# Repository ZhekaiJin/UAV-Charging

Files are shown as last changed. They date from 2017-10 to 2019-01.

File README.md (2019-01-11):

# UAV-Charging
Summer Intern Project for Totempower

* The circuit design could be viewed at the presentation
* Precise landing algorithm not disclosed here. (Contact me for full code)
* Full Info about Project [link](https://docs.google.com/presentation/d/1X8ElVUhhut9i08JShnHOG0T47P6EflJJdBkAeUSc1nc/edit?usp=sharing)

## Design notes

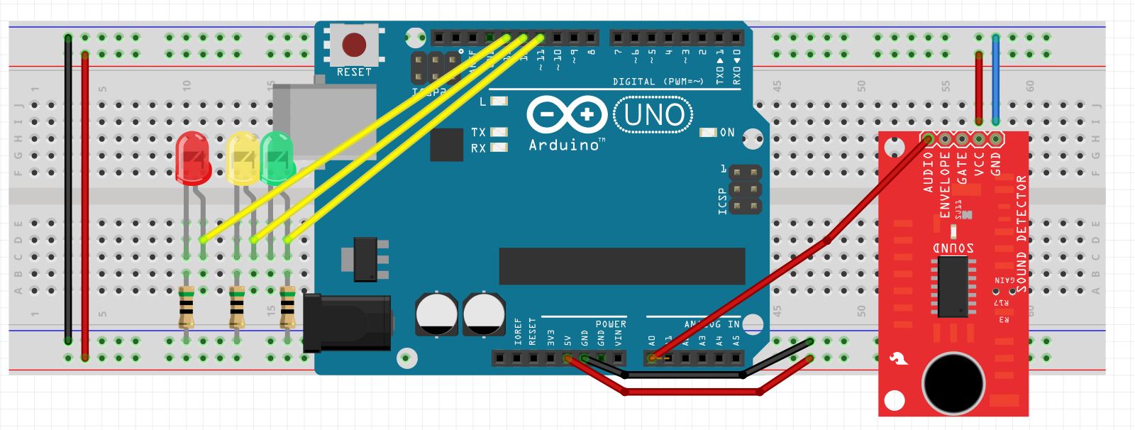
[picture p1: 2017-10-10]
Totem Project Zhekai Jin/realization 2/schematic.png

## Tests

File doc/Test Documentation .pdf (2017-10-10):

IDT WP3W-RK Testing Documentation

- Aiming to fully present all the features WP3W-RK implemented with WPC Qi Protocol
- connected with spark fun limo battery charging babysitter to implement charging for a single cell LiPo battery with 3.7V

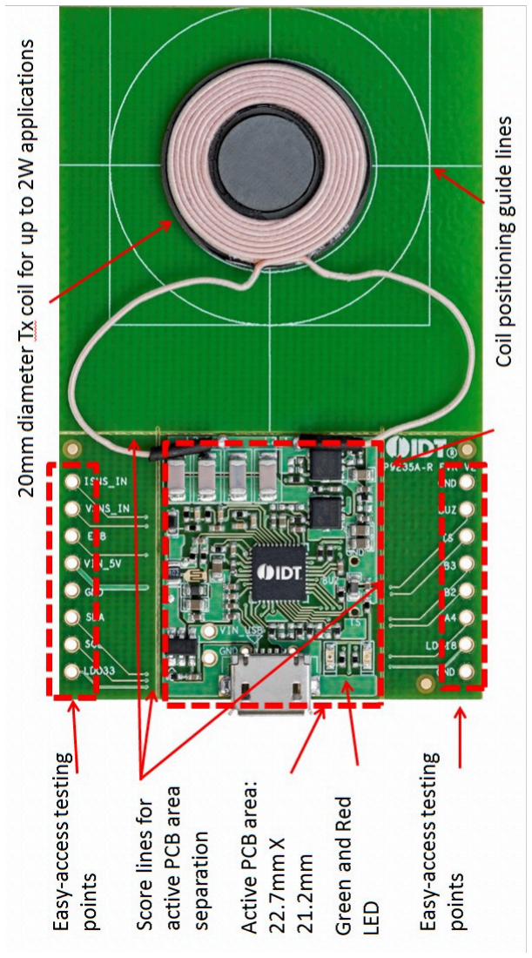
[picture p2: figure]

Transmitter

Pinout:

Vin_USB

Vin_5V

LDO 33

LDO 18

A4, B2,B3

BUZ

SDA

SCL

VSNS_IN

ISNS_IN

ENB

TS

GND

Receiver end:

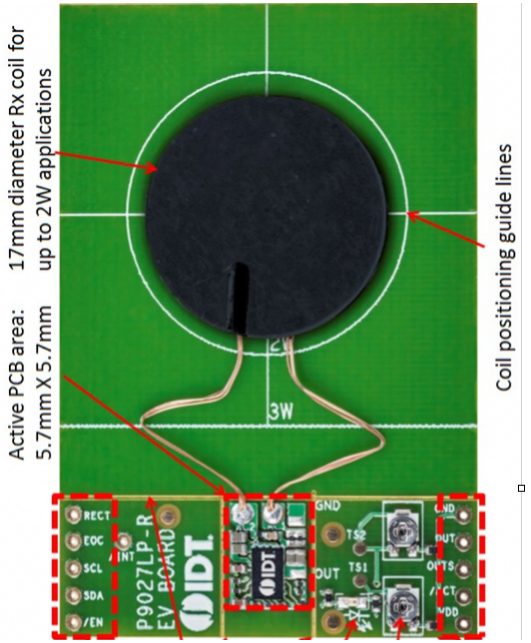
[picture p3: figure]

Pinout:

RECT

EOC

SCL

SDA

/EN

GND

OUT

OUTS

/ACT

VDD

Pinout specification(Transmitter):

Vin_USB | Micro usb power supply
Vin_5V | Input power supply (recommended 5V)
LDO 33 | Regulated 3.3 V output voltage used for internal device biasing.
LDO 18 | Regulated 1.8 V output voltage used for internal device biasing.
A4, B2,B3 | General purpose GPIO
BUZ | Buzzer pin output.
SDA /SCL | Data and Clock for I²C communication. Connect a 5.1 K resistor from this pin to VO_5
VSNS_IN | Voltage modulation signal input. (on test, just be the voltage sensing on the coil )
ISNS_IN | Current modulation signal input. (on test, just be the current sensing on the coil )
ENB | Active low enable pin. When connected to logic high, the device shuts down and consumes less than 25 µA of current. When connected to logic low, the device is in normal operation.
TS | Remote temperature sensing. Connect a 10 k NTC via a voltage divider to this pin.
GND | Ground connection

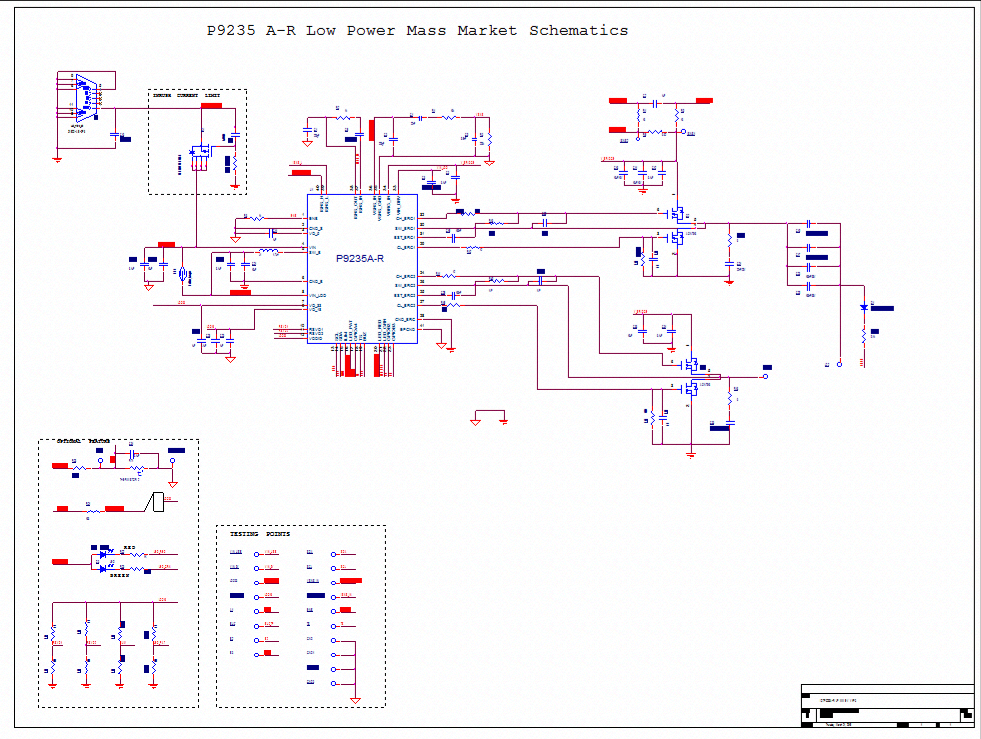
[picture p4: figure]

Transmitter Schematics

Tests on transmitter side:

- Basic functioning: Use a Micro USB connecter from the computer to power the transmitter, the red LED will blink once with the green led blink right after it, then both LEDs will light up for one second and turn off. When the receiver is put on the green LEDs on both the transmitter and the receiver will light up to show coupling

Power Consumption

Power the Transmitter with the Bench power supply (PSU, DC), if exactly 5V is supplied:

low power mode: voltage 5V current 0.01A when not in analog pinging and 0.03-0.05A(AC) in the pinging, according to estimate, the pinging is around 10 times per minute. (eye estimate)

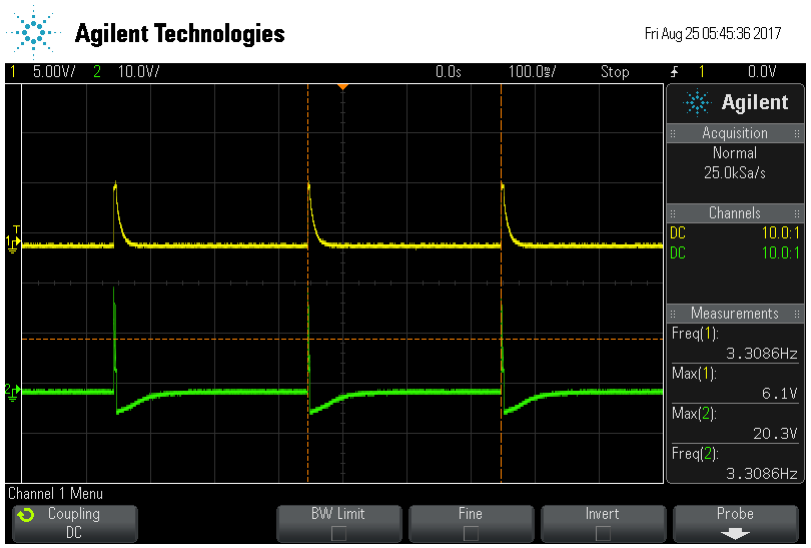
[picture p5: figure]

(Yellow from ISNS, Green from VSNS, Max scaled by 10X)

This demonstrates the analog pinging from the transmitter device to detect the presence of receiver coils. If the receiver is there, the transmitter will turn into digital pining to give enough energy pulse to active the receiver end circuit to start the handshake.

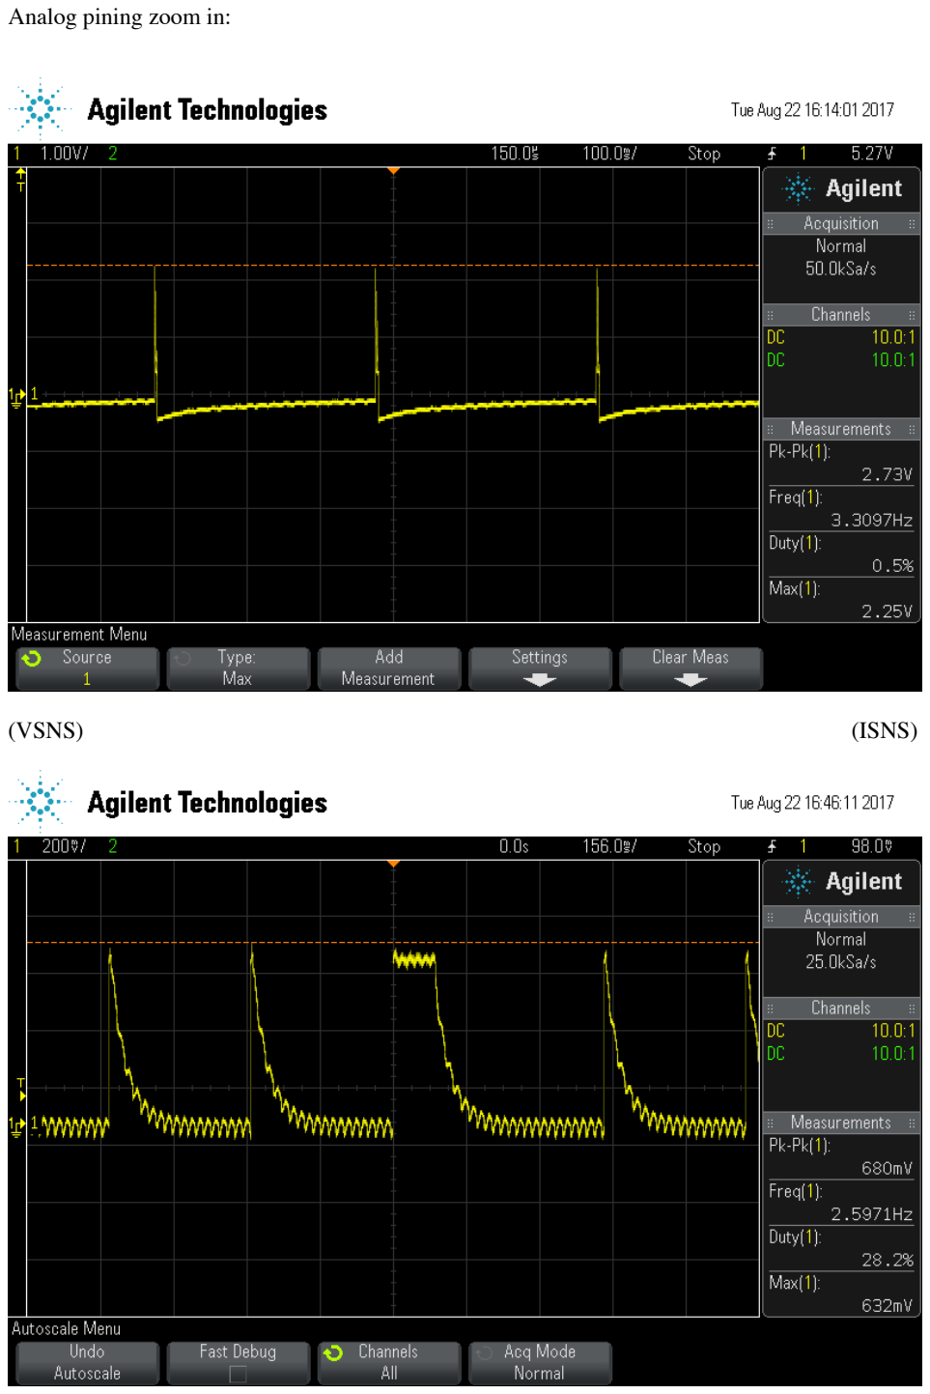
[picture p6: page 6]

Analog pining zoom in:

(VSNS) | (ISNS)

ISNS zoom in:

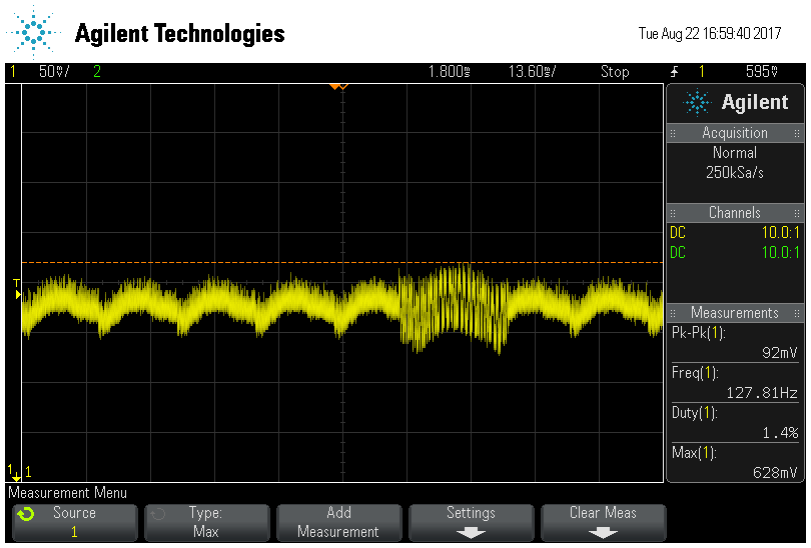
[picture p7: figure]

according to the acquired duty cycle the power consumption should be around 0.04 W (V*I *duty cycle) on the low power mode.

•by putting the receiver on the transmitter, a quick handshake should happen, with the digital pinging activate the device into identification and configuration phase where the Tx and Rx exchange information about protocol version and required voltage and maximum power output required. However, this process is too quick to capture on the Oscilloscope, will try to capture on future tests.

- the power transmission process then begin right after, with the receiver continuously sends back error packets on the coils back to the transmitter to fine-tune the power transmission. The received power packet can be viewed on the ISNS and VSNS both.

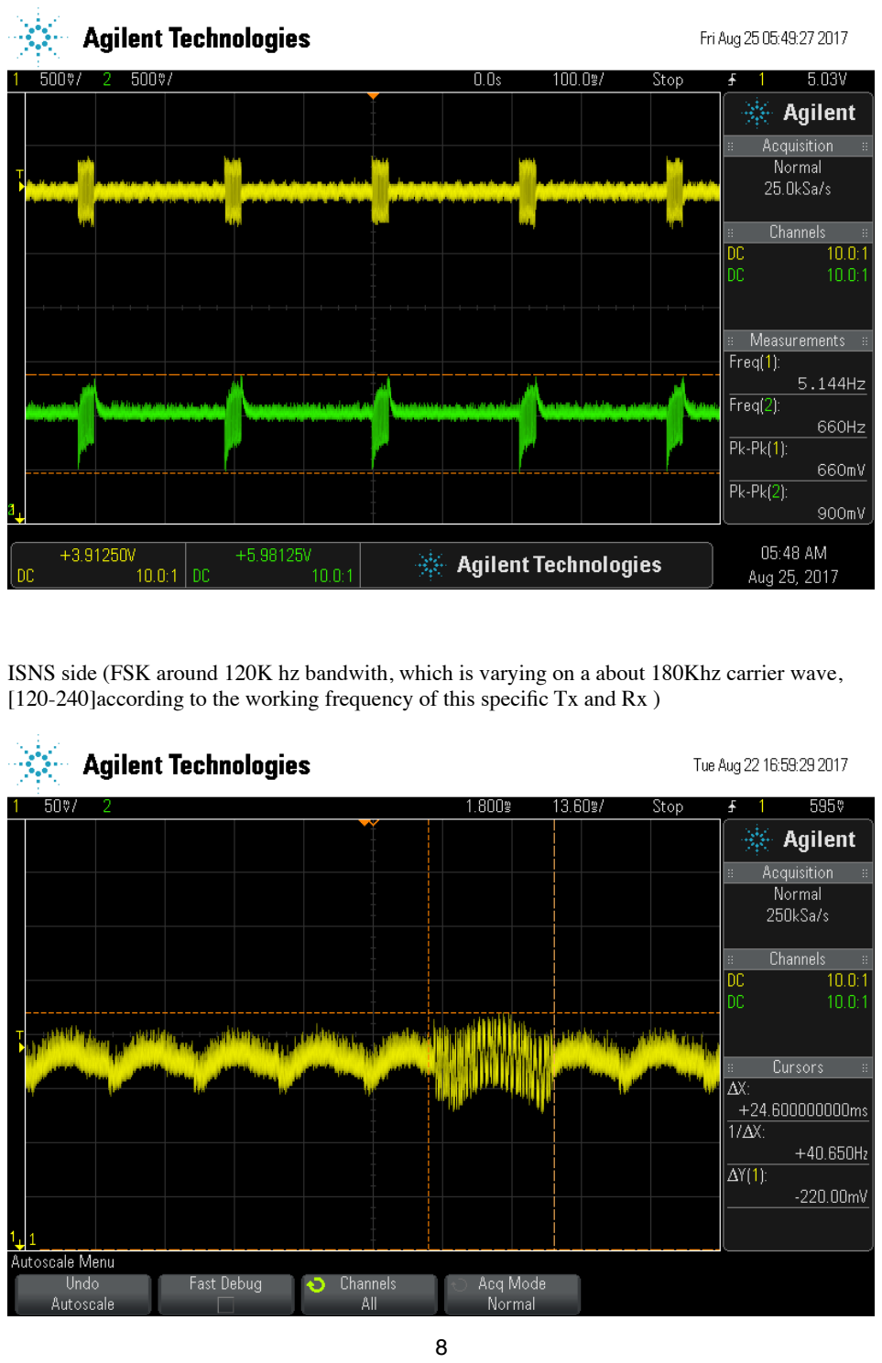
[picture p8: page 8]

ISNS side (FSK around 120K hz bandwith, which is varying on a about 180Khz carrier wave, [120-240]according to the working frequency of this specific Tx and Rx )

•On both sides

(Y for ISNS, G for VSNS)[10X mult]

to show the power transmission and the communication frequency.(packet frequency) [10X multi]

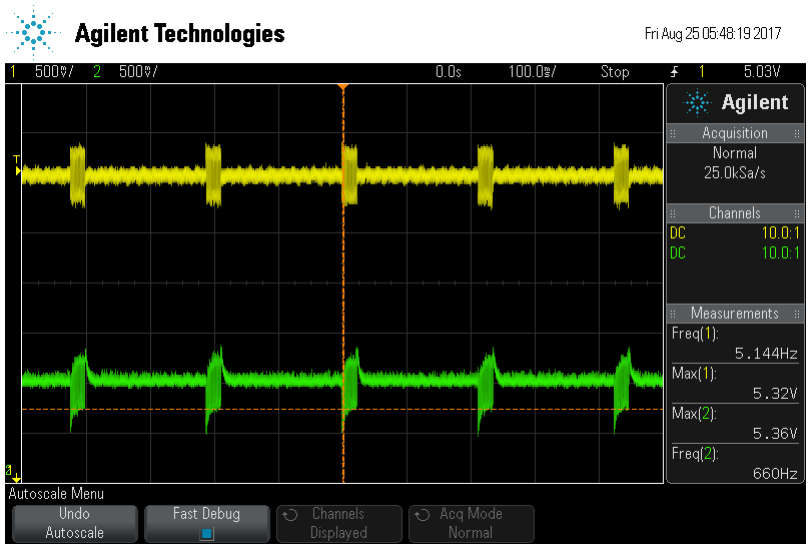
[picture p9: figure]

Observation from the PSU:

- coupling without load : Draw 0.17-0.22 A current from the power supply with no load (Vin >4.5V)
- coupling with load : Draw about 0.6 A current from the power supply with load on, around 3 W consumption from the load

Low Voltage alert : if the voltage is below 4.4V (from PSU), red LED will blink continuously to disallow charging, current will stay at 0.01 A without any pinging . if the supply is from 4.4 to 4.5 V, the pining will happen and no low power alert, but when coupling, and the signal strength packet is received, the coupling will stop (after 1s approximately), and the power transfer will sop and the transmitter goes into low power mode with red LED blinking (no pinging).

corresponding text in the data sheet :
“Under voltage protection: If the transmitter VIN is less than 4.5 V, the transmitter will

## shut down for five minutes, or until the VIN is cycled. off/on. “

High Voltage alert: if the voltage supplied is larger than 6.5V, the start up will be normal for the transmitter , but the receiver won’t allow coupling with the shake hand , the green LED on both devices wont even light up.

corresponding text in the data sheet :

## “Over voltage protection: If the transmitter VIN is greater than 5.5 V, and the system is

not in the Power Transfer mode, then the transmitter will shut down until the VIN is in the

## range of 4.5 V to 5.5 V. If the system is already in the Power Transfer mode, then the transmitter takes no action. “

- power consumption for the transmitter in low power mode : around 0.04 W

•LDO pinout voltage test: 3.3 and 1.8 V respectively, corresponding to the data sheet.

•BUZ: buzzer pin, untested

•ENB: =Enable Pin: If connected to high, power transmission of power will stop and the communication will turned to almost none value with 17mv AT MAXIMUM

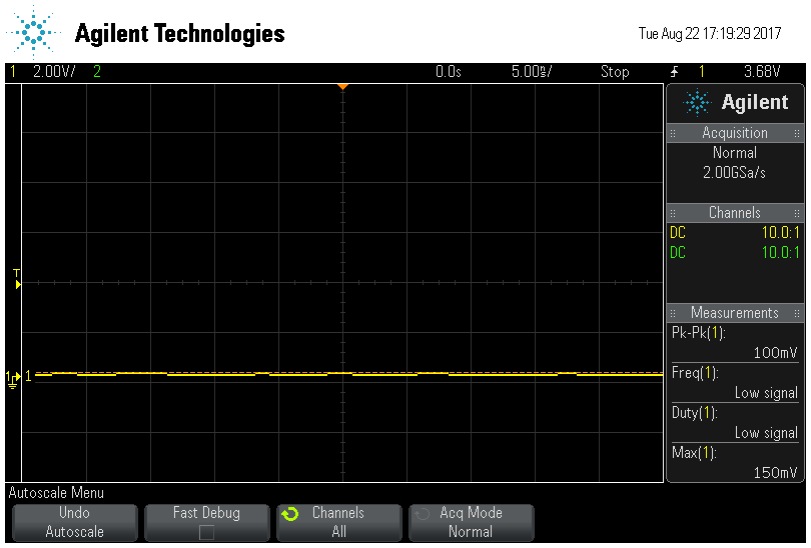
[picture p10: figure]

Receiver Pinout specification:

Pinout:
RECT | Output voltage of the synchronous rectifier bridge. Connect at least two 10 µF capacitors from this pin to PGND. The rectifier voltage dynamically changes as the load changes.
EOC | Active high end of charge input pin. When connected to logic high, the device sends end of power transfer packet (charge complete) to the transmitter to terminate power transfer and shuts down. The OUT pin is high impedance after P9027LP-R is shutdown
SCL | I 2C clock pin
SDA | I 2C data pin
/EN | Active low enable pin. Pulling this pin to logic high forces the device into shutdown mode. When connected to logic low, the device is enabled. Do not leave the pin floating.
GND | Power ground.
OUT | Regulated output voltage pin. Connect at least two 10 µF capacitors from this pin to PGND. The default voltage is set to 5V when VSET is directly shorted to GND.
OUTS | Feedback input pin. This pin must be connected directly to OUT pin to provide a regulated voltage.
/ACT | Active flag pin. Open drain output. Connect the cathode of the LED to this pin. When pulled low, it indicates connection between receiver and transmitter is established.
VDD | Charge pumps regulated 5 V supply to power the internal circuitry. Connect a 1 µF capacitor as close as possible from this pin to GND. Do not load the pin.

Schematics:

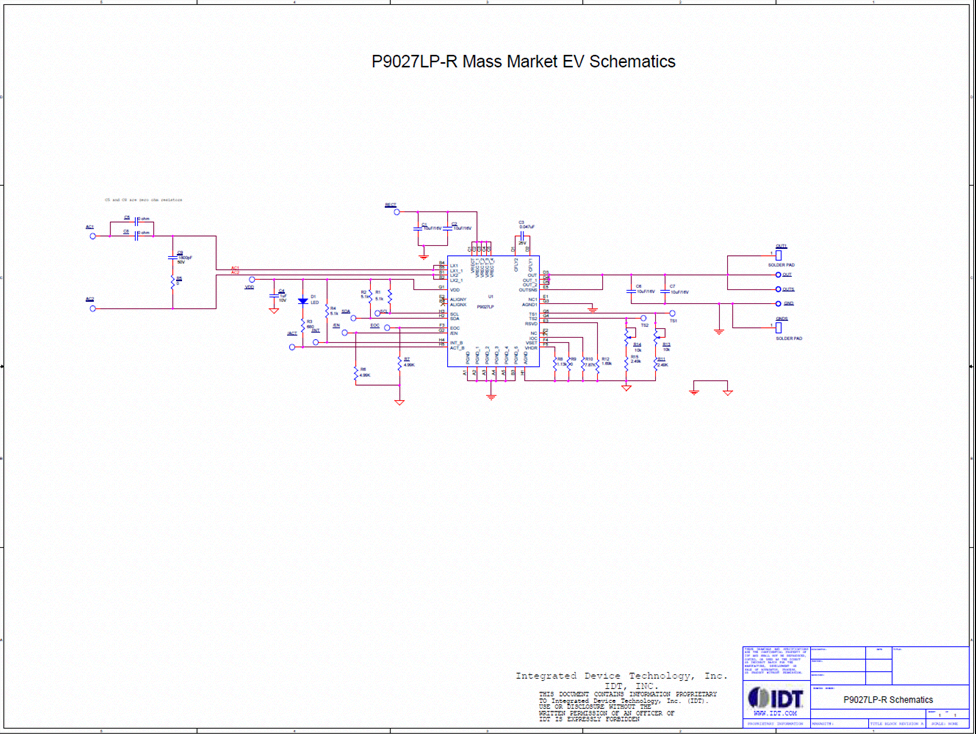
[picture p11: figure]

Tests:

•OUT pin

Test output without load:

with load: (OUT is Yellow, with OUTS green)

Doubt: the
schematic
showing they are
connected
together, however,
voltage difference
exists.

•Rect pin vs OUT pin : ( AC stands for the communication backwards, message encrypted before bridge)


•At same time, encrypted message FSK shown in ISNS.


•EOC pin, will send a end of power packet to the transmitter if connected to high.


the extra packet (the second right following the first over the continuous regular received packet) in the graph following RECT DC value drops but stills in communication with VSNS and ISNS still has pinging and packets transfer in between.

(Y for ISNS, G for VSNS)

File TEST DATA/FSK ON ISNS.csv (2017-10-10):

x-axis | 1
second | Volt
-440.0000E-09 | +578.0678540468E-03
-439.5000E-09 | +579.6758942306E-03
-439.0000E-09 | +579.6758942306E-03
-438.5000E-09 | +579.6758942306E-03
-438.0000E-09 | +579.6758942306E-03
-437.5000E-09 | +579.6758942306E-03
-437.0000E-09 | +579.6758942306E-03
-436.5000E-09 | +578.1683565583E-03
-436.0000E-09 | +578.0678540468E-03
-435.5000E-09 | +578.0678540468E-03
-435.0000E-09 | +578.0678540468E-03
-434.5000E-09 | +578.0678540468E-03
-434.0000E-09 | +578.0678540468E-03
-433.5000E-09 | +578.0678540468E-03
-433.0000E-09 | +578.0678540468E-03
-432.5000E-09 | +578.0678540468E-03
-432.0000E-09 | +576.5603163745E-03
-431.5000E-09 | +576.4598138630E-03
-431.0000E-09 | +576.4598138630E-03
-430.5000E-09 | +576.4598138630E-03
-430.0000E-09 | +578.0678540468E-03
-429.5000E-09 | +578.0678540468E-03
-429.0000E-09 | +579.6758942306E-03
-428.5000E-09 | +579.6758942306E-03
-428.0000E-09 | +579.6758942306E-03
-427.5000E-09 | +579.6758942306E-03
-427.0000E-09 | +579.6758942306E-03
-426.5000E-09 | +578.1683565583E-03
-426.0000E-09 | +578.0678540468E-03
-425.5000E-09 | +578.0678540468E-03
-425.0000E-09 | +576.5603163745E-03
-424.5000E-09 | +576.4598138630E-03
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

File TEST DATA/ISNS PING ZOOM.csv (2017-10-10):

x-axis | 1
second | Volt
-310.0000E-03 | -20.8354E-03
-309.6900E-03 | -30.8857E-03
-309.3800E-03 | -32.8957E-03
-309.0700E-03 | -38.6746E-03
-308.7600E-03 | -32.6445E-03
-308.4500E-03 | -34.9058E-03
-308.1400E-03 | -32.8957E-03
-307.8300E-03 | -30.8857E-03
-307.5200E-03 | -32.8957E-03
-307.2100E-03 | -30.6344E-03
-306.9000E-03 | -28.8756E-03
-306.5900E-03 | -28.8756E-03
-306.2800E-03 | -24.8555E-03
-305.9700E-03 | -24.8555E-03
-305.6600E-03 | -20.8354E-03
-305.3500E-03 | -18.8254E-03
-305.0400E-03 | -8.7751E-03
-304.7300E-03 | -6.5138E-03
-304.4200E-03 | -4.7550E-03
-304.1100E-03 | -2.7450E-03
-303.8000E-03 | -4.7550E-03
-303.4900E-03 | -734.9E-06
-303.1800E-03 | +3.2852E-03
-302.8700E-03 | +3.2852E-03
-302.5600E-03 | +3.2852E-03
-302.2500E-03 | +7.3053E-03
-301.9400E-03 | +11.3254E-03
-301.6300E-03 | +11.3254E-03
-301.3200E-03 | +15.3455E-03
-301.0100E-03 | +15.5967E-03
-300.7000E-03 | +19.3656E-03
-300.3900E-03 | +15.3455E-03
-300.0800E-03 | +19.3656E-03
-299.7700E-03 | +15.3455E-03
-299.4600E-03 | +15.3455E-03
-299.1500E-03 | +13.5867E-03
-298.8400E-03 | +11.3254E-03
-298.5300E-03 | +13.5867E-03
-298.2200E-03 | +11.3254E-03
-297.9100E-03 | +9.5666E-03
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

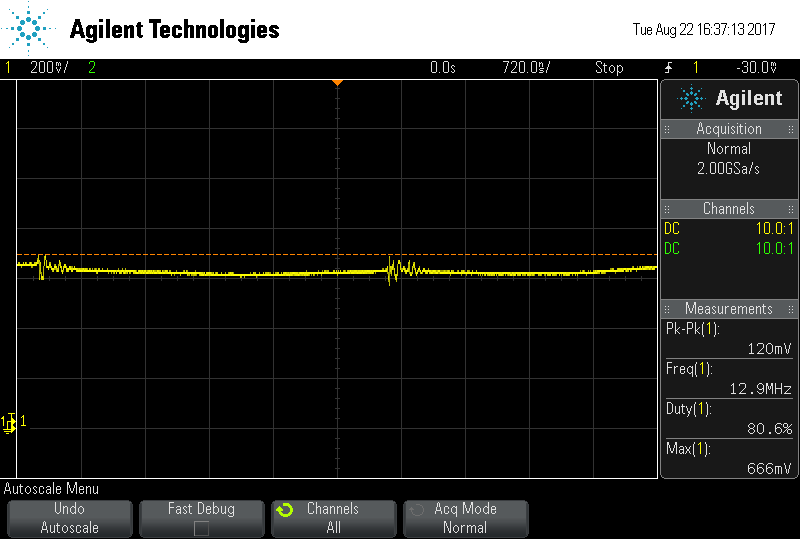
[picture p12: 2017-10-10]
TEST DATA/VSNS TM.png

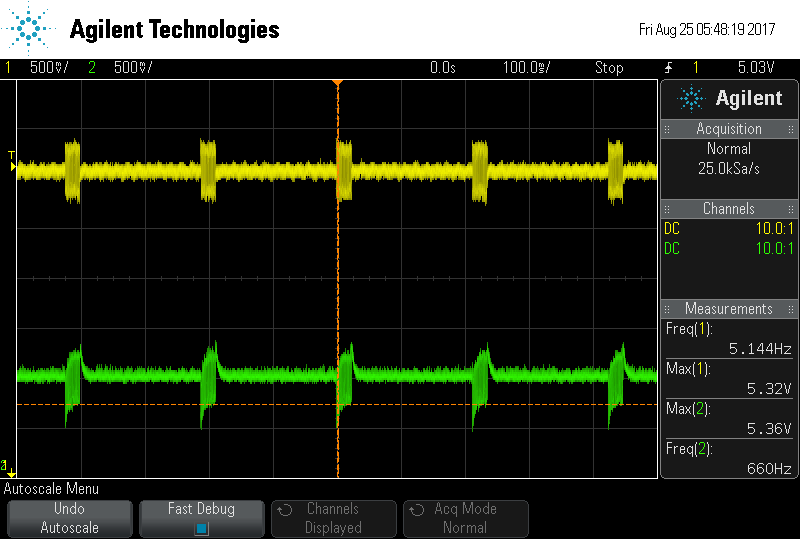
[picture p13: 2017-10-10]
TEST DATA/VSNS &ISNS.png

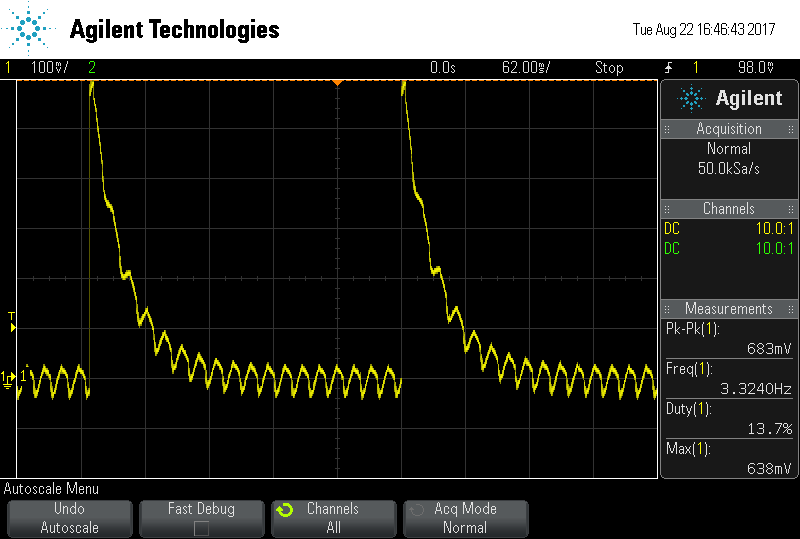
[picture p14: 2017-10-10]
TEST DATA/ISNS PING ZOOM.png

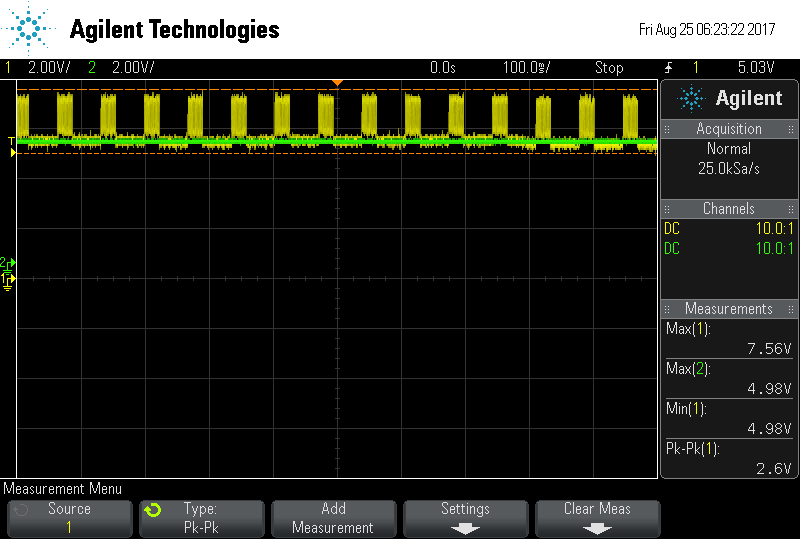
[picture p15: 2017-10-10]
TEST DATA/RECT VS OUT.png

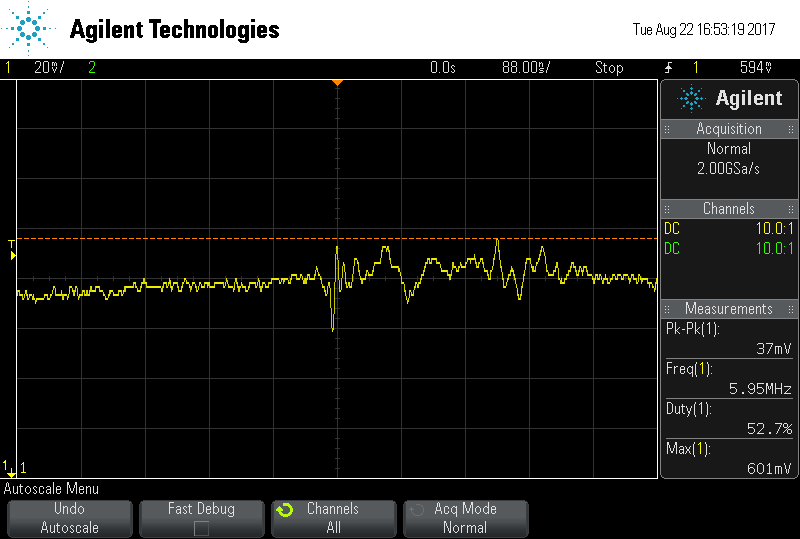
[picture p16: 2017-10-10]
TEST DATA/FSK ON ISNS.png

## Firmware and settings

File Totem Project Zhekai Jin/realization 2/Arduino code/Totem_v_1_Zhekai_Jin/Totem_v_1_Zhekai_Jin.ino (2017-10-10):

// define the pin connections first 
const int microphonePin= A0; //the microphone positive terminal will connect to analog pin A0 to be read
const int Red=13; //define the three LED determing noise level
const int Yellow=12;
const int Green=11;

int sample; //the variable that will hold the value read from the microphone each time

const double AnalogQuiet = 50; // define boundary condition for three cases
const double AnalogModerate = 400;
const double AnalogLoud = 1022;

void setup() {
    pinMode (Red, OUTPUT); // put pins  to output mode for lED output
    pinMode (Yellow, OUTPUT);
    pinMode (Green, OUTPUT);
    Serial.begin(9600); //coordinate with serial monitor 
    while (! Serial); 
    Serial.println("Enter 'x' to start");
}

//Serial.println(sample);
void loop(){
  if (Serial.available()){
      digitalWrite (Green, LOW);    // specify LED conditions
      digitalWrite(Yellow, LOW);
      digitalWrite(Red, LOW);
      char ch = Serial.read();
      if (ch == 'x'){
         while(1){
            sample= analogRead(microphonePin); //the arduino takes continuous readings from the microphone
            if ((sample > AnalogQuiet) && (sample < AnalogModerate))  //if the reading is greater than the threshold value, LED turns on
            {
                digitalWrite (Green, HIGH);    // specify LED conditions
                digitalWrite(Yellow, LOW);
                digitalWrite(Red, LOW);
            
                delay (50);         //LED stays on for a 0.05 s
                digitalWrite (Green, LOW);  //LED turns off
                
                Serial.print("Quiet. Value: ");   // input to serial monitor
                Serial.print(sample);
                Serial.print('\n');
            
            }
             else if ((sample > AnalogModerate) && ( sample <= AnalogLoud) )  // same case for the moderate volume
             {
                digitalWrite(Green, LOW);
                digitalWrite(Yellow, HIGH);
                digitalWrite(Red, LOW);
                delay (50); 
                digitalWrite (Yellow, LOW); 
                
                Serial.print("Moderate. Value: ");
                Serial.print(sample);
                Serial.print('\n');
            } 
            
             else if (sample> AnalogLoud )   // same case for the moderate volume
             
             {
                digitalWrite(Green, LOW);
                digitalWrite(Yellow, LOW);
                digitalWrite(Red, HIGH);
                delay (50); //LED stays on for a 0.05 s
                digitalWrite (Red, LOW); //LED turns off
                
                Serial.print("Loud. Value: ");
                Serial.print(sample);
                Serial.print('\n');
            
             }
          }
       }
    }
}  

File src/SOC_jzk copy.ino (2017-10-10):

/******************************************************************************
BQ27441_GPOUT_SOC_INT
BQ27441 Library GPOUT Example - State-of-charge interval mode
Jim Lindblom @ SparkFun Electronics
May 9, 2016
https://github.com/sparkfun/SparkFun_BQ27441_Arduino_Library

Demonstrates how to use the BQ27441's SOC_INT function on GPOUT. In this mode
GPOUT will pulse every time the state-of-charge (soc) goes up or down by a 
set percentage integer.

In addition to I2C, connect GPOUT to pin 2 of your Arduino.

After uploading, open up the serial monitor to 115200 baud to view your 
battery's stats. They should only print when the percentage goes up or down
by 1%.

Hardware Resources:
- Arduino Development Board
- SparkFun Battery Babysitter

Development environment specifics:
Arduino 1.6.7
SparkFun Battery Babysitter v1.0
Arduino Uno (any 'duino should do)
******************************************************************************/
#include <SparkFunBQ27441.h>

// Set BATTERY_CAPACITY to the design capacity of your battery.
const unsigned int BATTERY_CAPACITY = 1200; // e.g. 850mAh battery

// Arduino pin connected to BQ27441's GPOUT pin
const int GPOUT_PIN = 2;

// Set the integer percentage change that triggers an interrupt
const int PERCENTAGE_INTERVAL = 1;

void setupBQ27441(void)
{
  pinMode(GPOUT_PIN, INPUT_PULLUP); // Set the GPOUT pin as an input w/ pullup
  
  // Use lipo.begin() to initialize the BQ27441-G1A and confirm that it's
  // connected and communicating.
  if (!lipo.begin()) // begin() will return true if communication is successful
  {
	// If communication fails, print an error message and loop forever.
    Serial.println("Error: Unable to communicate with BQ27441.");
    Serial.println("  Check wiring and try again.");
    Serial.println("  (Battery must be plugged into Battery Babysitter!)");
    while (1) ;
  }
  //Serial.println("Connected to BQ27441!");

  // In this example, we'll manually enter and exit config mode. By controlling
  // config mode manually, you can set the chip up faster -- completing all of
  // the set up in a single config mode sweep.
  lipo.enterConfig(); // To configure the values below, you must be in config mode
  lipo.setCapacity(BATTERY_CAPACITY); // Set the battery capacity
  lipo.setGPOUTPolarity(LOW); // Set GPOUT to active-low
  lipo.setGPOUTFunction(SOC_INT); // Set GPOUT to SOC_INT mode
  lipo.setSOCIDelta(PERCENTAGE_INTERVAL); // Set percentage change integer
  lipo.exitConfig(); // Exit config mode to save changes

  // Use lipo.GPOUTPolarity to read from the chip and confirm the changes
  if (lipo.GPOUTPolarity())
    //Serial.println("GPOUT set to active-HIGH");
    delay(1);
  else
    //Serial.println("GPOUT set to active-LOW");

  // Use lipo.GPOUTFunction to confirm the functionality of GPOUT
  if (lipo.GPOUTFunction())
    //Serial.println("GPOUT function set to BAT_LOW");
    delay(1);
  else
    //Serial.println("GPOUT function set to SOC_INT");
  
  // Read lipo.sociDelta() to confirm the integer change value
  
  //Serial.println("SOCI Delta: " + String(lipo.sociDelta()));
  //Serial.println();
  
  // Use lipo.pulseGPOUT() to trigger a pulse on GPOUT. This only works
  // in SOC_INT mode.
  
  //Serial.println("Testing GPOUT Pulse");
  lipo.pulseGPOUT();
  int timeout = 10000; // The pulse can take a while to occur. Set max to 10s
  while ((digitalRead(GPOUT_PIN)) && timeout--)
    delay(1); // Wait for GPOUT to go high, or timeout to occur
  if (timeout > 0) 
  {
	// If GPOUT pulsed, print success message.
    
    //Serial.print("GPOUT test successful!");
    //Serial.println("(" + String(10000 - timeout) + ")");
    //Serial.print("GPOUT will pulse whenever the SoC ");
    //Serial.println("value changes by SOCI delta.");
    //Serial.print("Or when the battery changes from");
    //Serial.println(" charging to discharging, or vice-versa.");
    //Serial.println();
  }
  else
  {
	// If GPOUT didn't pulse, something went wrong. Print error message
	// and loop forever.
    
    Serial.println("GPOUT didn't pulse.");
    Serial.print("Make sure it's connected to pin ");
    Serial.print(GPOUT_PIN);
    Serial.println(" and reset.");
    while (1) ;
    
  }
}

void printBatteryStats()
{
  // Read battery stats from the BQ27441-G1A
  unsigned int soc = lipo.soc();  // Read state-of-charge (%)
  unsigned int volts = lipo.voltage(); // Read battery voltage (mV)
  int current = lipo.current(AVG); // Read average current (mA)
  unsigned int fullCapacity = lipo.capacity(FULL); // Read full capacity (mAh)
  unsigned int capacity = lipo.capacity(REMAIN); // Read remaining capacity (mAh)
  int power = lipo.power(); // Read average power draw (mW)
  int health = lipo.soh(); // Read state-of-health (%)

  // Assemble a string to print
  String toPrint;
  toPrint += String(soc) + "% | ";
  toPrint += String(volts) + " mV | ";
  toPrint += String(current) + " mA | ";
  toPrint += String(capacity) + " / ";
  toPrint += String(fullCapacity) + " mAh | ";
  toPrint += String(power) + " mW | ";
  toPrint += String(health) + "% |";
  toPrint += String(millis()/1000) ;
  
  // Print the string
  Serial.println(toPrint);
}

void setup()
{
  Serial.begin(115200);  
  setupBQ27441();
}

void loop() 
{
  // The interrupt is set to active-low. If the GPOUT pin goes low...
  if (digitalRead(GPOUT_PIN) == LOW)
  {
	// ...SOC_INT occurred. Print battery stats.
    printBatteryStats();
  }
}
